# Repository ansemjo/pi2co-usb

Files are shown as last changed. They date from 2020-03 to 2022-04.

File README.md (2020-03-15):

# pi2co-usb

This project is based on [i2c-tiny-usb](https://github.com/harbaum/I2C-Tiny-USB/) by Till Harbaum and the [V-USB stack](https://www.obdev.at/products/vusb/index.html) by Objective Development. It uses the fact that you can implement a low-speed USB device with the IO pins on an Atmel AVR chip to create a very simple I2C bridge.

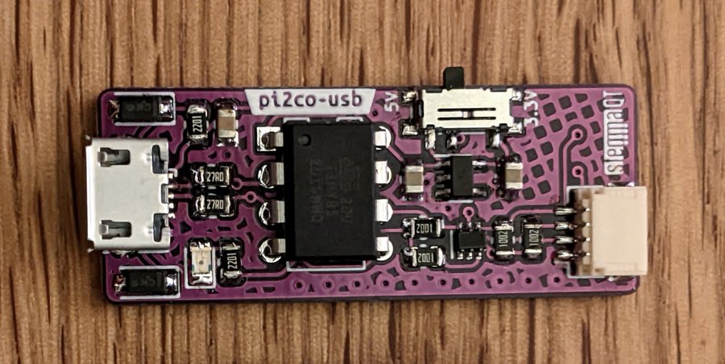
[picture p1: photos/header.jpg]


## Hardware

In the original `i2c-tiny-usb` implementation, an Atmel AVR ATtiny45 was used with an external oscillator. Unfortunately this meant, that you needed to use all six pins on the chip, reconfigure the RESET pin and therefore needed a high-voltage serial programmer (HVSP) should anything go wrong.

On more recent Digispark devices, which use an ATtiny85, a modified version of the V-USB stack is used with only the internal PLL oscillator calibrated to 16.5 MHz. No external chrystal is required, ISP remains available and you can even connect an indicator LED on the remaining pin.

I had a couple of Atmel AVR ATtiny85V-10PU chips and a small leftover piece of protoboard. Enough to build myself an I2C bridge! I used a JST-PH connector on the I2C side, which has a slightly too narrow pitch but it works out with a 4-pin connector if you solder it at the edge of the board. Also I had lots of connectors, so I could crimp myself some cables.

Here is a simple [schematic](schematic.pdf) of the protoboard version that you see below on the photos:



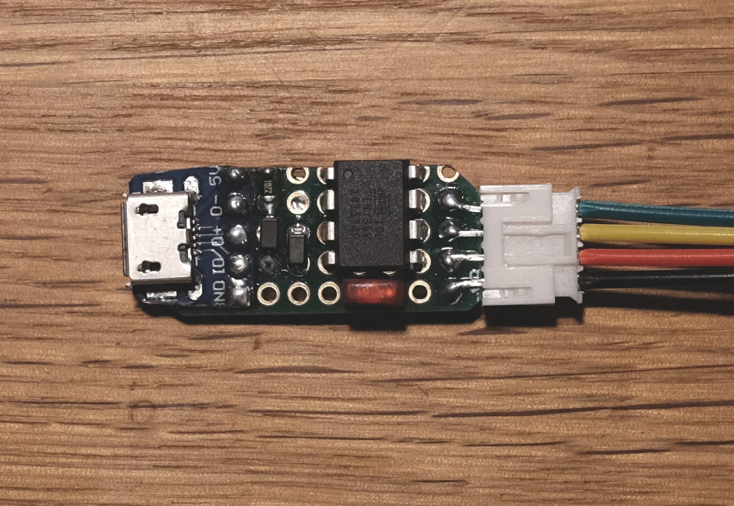
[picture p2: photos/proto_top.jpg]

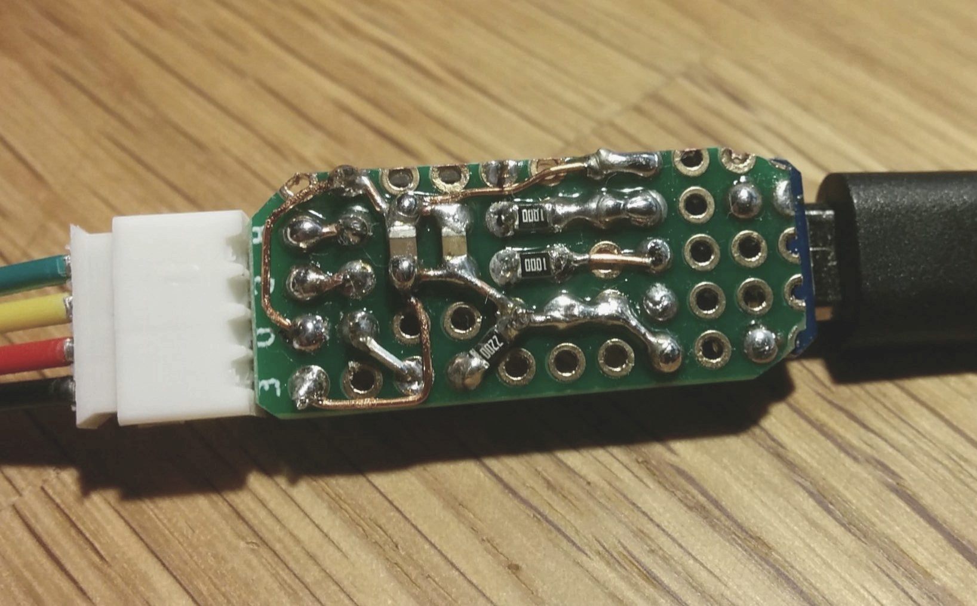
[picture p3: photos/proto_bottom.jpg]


## Software

The firmware is almost fully plucked from Till Harbaum's `i2c-tiny-usb` project, so most credit goes to him. I converted the directory to a PlatformIO project, updated the vendored V-USB stack and modified the configuration header to use a different pinout.

It is meant to work together with a current [micronucleus](https://github.com/micronucleus/micronucleus/) bootloader, which allows loading new firmware over the same USB port that is used in the userspace firmware. This implementation also relies on the oscillator calibration included in the bootloader to achieve a stable 16.5 MHz clock.

### Flash the Bootloader

At first I used a default release for the ATtiny85 that I flashed with an ISP programmer and later changed a few options to enable the indicator LED, enter the bootloader only after shorting the RESET pin and disable the timeout. The configuration can be found in `bootloader/t85_pi2co` and can be linked or copied to a micronucleus project under `firmware/configuration/`.

For example, to compile the firmware with the config profile above and flash it with an [Adafruit FT232H breakout](https://wiki.semjonov.de/tips/arduino.html#adafruit-ftdi-ft232h-breakout-board):

```sh
make clean
make CONFIG=t85_pi2co
make CONFIG=t85_pi2co PROGRAMMER="-c ft232h" flash
make CONFIG=t85_pi2co PROGRAMMER="-c ft232h" fuse
```

After that you should be able to speak to the chip with the `micronucleus` commandline application if you connect a USB breakout appropriately. **To enter the bootloader later**, you'll need to reset the chip by briefly shorting the RESET pin to ground.

To allow normal users to speak with the bootloader, apply the
udev rules found in [49-micronucleus.rules](https://github.com/micronucleus/micronucleus/blob/e74ce6f064e0bcbe1c52459a0988187c76834222/commandline/49-micronucleus.rules).

### Flash the Firmware

Now that the bootloader works, install [PlatformIO](https://platformio.org/) and go to the `firmware/` directory. You can now compile the firmware simply by running `pio run`. PlatformIO should handle all framework and platform dependencies for you.

Afterwards flash the firmware by running:

```sh
pio run -t upload
```

**Note:** PlatformIO currently ships an outdated version of the `micronucleus` commandline tool, which won't speak to the current bootloader releases. Either update the binary in `~/.platformio/packages/tool-micronucleus/` or use a current binary with the compiled firmware directly:

```sh
micronucleus .pio/build/tiny85/firmware.hex
```

### Kernel driver

The `i2c-tiny-usb` project has been around for a while, so it already has a driver in the mainline Linux kernel. I only needed to `modprobe i2c-dev` for the device to appear. Install the `i2c-tools` in your Linux distribution of choice and start talking to I2C devices. You may need to run the tools as `root`.

As an example I am reading the date and time from a DS3231 RTC clock:

```sh
$ sudo i2cdetect -l
[sudo] password for ansemjo: 
/* ... */
i2c-10	i2c       	i2c-tiny-usb at bus 001 device 028	I2C adapter
/* ... */

$ sudo i2cdetect -y 10
     0  1  2  3  4  5  6  7  8  9  a  b  c  d  e  f
00:          -- -- -- -- -- -- -- -- -- -- -- -- -- 
10: -- -- -- -- -- -- -- -- -- -- -- -- -- -- -- -- 
20: -- -- -- -- -- -- -- -- -- -- -- -- -- -- -- -- 
30: -- -- -- -- -- -- -- -- -- -- -- -- -- -- -- -- 
40: -- -- -- -- -- -- -- -- -- -- -- -- -- -- -- -- 
50: -- -- -- -- -- -- -- 57 -- -- -- -- -- -- -- -- 
60: -- -- -- -- -- -- -- -- 68 -- -- -- -- -- -- --  << this is the rtc
70: -- -- -- -- -- -- -- --                         

$ i=0; for value in seconds minutes hours weekday day month year; do \
> printf '%7s: %s\n' $value "$(sudo i2cget -y 10 0x68 $i)"; : $((i++)); done
seconds: 0x39
minutes: 0x07
  hours: 0x19
weekday: 0x07
    day: 0x15
  month: 0x03
   year: 0x20
```

The bytes need BCD decoding but you can see the date was `2020-03-15 19:07:39`.

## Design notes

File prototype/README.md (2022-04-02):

# pi2co-usb

This project is based on [i2c-tiny-usb](https://github.com/harbaum/I2C-Tiny-USB/) by Till Harbaum and the [V-USB stack](https://www.obdev.at/products/vusb/index.html) by Objective Development. It uses the fact that you can implement a low-speed USB device with the IO pins on an Atmel AVR chip to create a very simple I2C bridge.

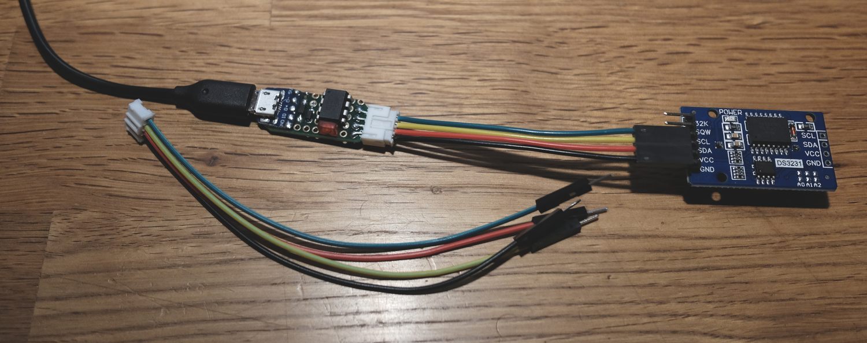
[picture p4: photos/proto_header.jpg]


## Hardware

In the original `i2c-tiny-usb` implementation, an Atmel AVR ATtiny45 was used with an external oscillator. Unfortunately this meant, that you needed to use all six pins on the chip, reconfigure the RESET pin and therefore needed a high-voltage serial programmer (HVSP) should anything go wrong.

On more recent Digispark devices, which use an ATtiny85, a modified version of the V-USB stack is used with only the internal PLL oscillator calibrated to 16.5 MHz. No external chrystal is required, ISP remains available and you can even connect an indicator LED on the remaining pin.

I had a couple of Atmel AVR ATtiny85V-10PU chips and a small leftover piece of protoboard. Enough to build myself an I2C bridge! I used a JST-PH connector on the I2C side, which has a slightly too narrow pitch but it works out with a 4-pin connector if you solder it at the edge of the board. Also I had lots of connectors, so I could crimp myself some cables.

Here is a simple [schematic](schematic.pdf) of the protoboard version that you see below on the photos:






## Software

The firmware is almost fully plucked from Till Harbaum's `i2c-tiny-usb` project, so most credit goes to him. I converted the directory to a PlatformIO project, updated the vendored V-USB stack and modified the configuration header to use a different pinout.

It is meant to work together with a current [micronucleus](https://github.com/micronucleus/micronucleus/) bootloader, which allows loading new firmware over the same USB port that is used in the userspace firmware. This implementation also relies on the oscillator calibration included in the bootloader to achieve a stable 16.5 MHz clock.

### Flash the Bootloader

At first I used a default release for the ATtiny85 that I flashed with an ISP programmer and later changed a few options to enable the indicator LED, enter the bootloader only after shorting the RESET pin and disable the timeout. The configuration can be found in `bootloader/t85_pi2co` and can be linked or copied to a micronucleus project under `firmware/configuration/`.

For example, to compile the firmware with the config profile above and flash it with an [Adafruit FT232H breakout](https://wiki.semjonov.de/tips/arduino.html#adafruit-ftdi-ft232h-breakout-board):

```sh
make clean
make CONFIG=t85_pi2co
make CONFIG=t85_pi2co PROGRAMMER="-c ft232h" flash
make CONFIG=t85_pi2co PROGRAMMER="-c ft232h" fuse
```

After that you should be able to speak to the chip with the `micronucleus` commandline application if you connect a USB breakout appropriately. **To enter the bootloader later**, you'll need to reset the chip by briefly shorting the RESET pin to ground.

To allow normal users to speak with the bootloader, apply the
udev rules found in [49-micronucleus.rules](https://github.com/micronucleus/micronucleus/blob/e74ce6f064e0bcbe1c52459a0988187c76834222/commandline/49-micronucleus.rules).

### Flash the Firmware

Now that the bootloader works, install [PlatformIO](https://platformio.org/) and go to the `firmware/` directory. You can now compile the firmware simply by running `pio run`. PlatformIO should handle all framework and platform dependencies for you.

Afterwards flash the firmware by running:

```sh
pio run -t upload
```

**Note:** PlatformIO currently ships an outdated version of the `micronucleus` commandline tool, which won't speak to the current bootloader releases. Either update the binary in `~/.platformio/packages/tool-micronucleus/` or use a current binary with the compiled firmware directly:

```sh
micronucleus .pio/build/tiny85/firmware.hex
```

### Kernel driver

The `i2c-tiny-usb` project has been around for a while, so it already has a driver in the mainline Linux kernel. I only needed to `modprobe i2c-dev` for the device to appear. Install the `i2c-tools` in your Linux distribution of choice and start talking to I2C devices. You may need to run the tools as `root`.

As an example I am reading the date and time from a DS3231 RTC clock:

```sh
$ sudo i2cdetect -l
[sudo] password for ansemjo: 
/* ... */
i2c-10	i2c       	i2c-tiny-usb at bus 001 device 028	I2C adapter
/* ... */

$ sudo i2cdetect -y 10
     0  1  2  3  4  5  6  7  8  9  a  b  c  d  e  f
00:          -- -- -- -- -- -- -- -- -- -- -- -- -- 
10: -- -- -- -- -- -- -- -- -- -- -- -- -- -- -- -- 
20: -- -- -- -- -- -- -- -- -- -- -- -- -- -- -- -- 
30: -- -- -- -- -- -- -- -- -- -- -- -- -- -- -- -- 
40: -- -- -- -- -- -- -- -- -- -- -- -- -- -- -- -- 
50: -- -- -- -- -- -- -- 57 -- -- -- -- -- -- -- -- 
60: -- -- -- -- -- -- -- -- 68 -- -- -- -- -- -- --  << this is the rtc
70: -- -- -- -- -- -- -- --                         

$ i=0; for value in seconds minutes hours weekday day month year; do \
> printf '%7s: %s\n' $value "$(sudo i2cget -y 10 0x68 $i)"; : $((i++)); done
seconds: 0x39
minutes: 0x07
  hours: 0x19
weekday: 0x07
    day: 0x15
  month: 0x03
   year: 0x20
```

The bytes need BCD decoding but you can see the date was `2020-03-15 19:07:39`.

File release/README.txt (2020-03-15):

These release files were compiled on 2020-03-15 using the steps
detailed in the project's README.md.

01. Flash the Bootloader
========================

First, flash the bootloader with your favourite ISP programming
method with avrdude. Personally, I like using an Adafruit FT232H
breakout for this:

  avrdude -c UM232H -p t85 -U flash:w:bootloader.hex:i

Don't forget to set the fuses if this is the first time flashing
micronucleus:

  avrdude -c UM232H -p t85 \
    -U lfuse:w:0xe1:m -U hfuse:w:0xdd:m -U efuse:w:0xfe:m

02. Verify USB connection
=========================

Connect a USB breakout to the ATtiny85 to verify that the command-
line tool can speak to the micronucleus bootloader. The pull-up
resistor on D- is required but depending on your computer you may
be fine without the zener diodes. This is not to specification though!

  VCC -->  VCC (pin 8)
  D-  -->  PB3 (pin 2)
  D+  -->  PB4 (pin 3)
  GND -->  GND (pin 4)

You should see a device appear on the bus and micronucleus should
be able to program the chip:

  micronucleus --erase-only

03. Upload the Firmware
=======================

Now use micronucleus to upload the firmware:

  micronucleus ./firmware.hex

After you have uploaded the firmware and replugged the USB cable, the
chip should execute the firmware immediately and the i2c-tiny-usb
should appear on the bus:

  ID 0403:c631 Future Technology Devices International, Ltd i2c-tiny-usb interface

To re-enter the bootloader, briefly short the RESET pin (pin 1) to
GND with some tweezers, for example.

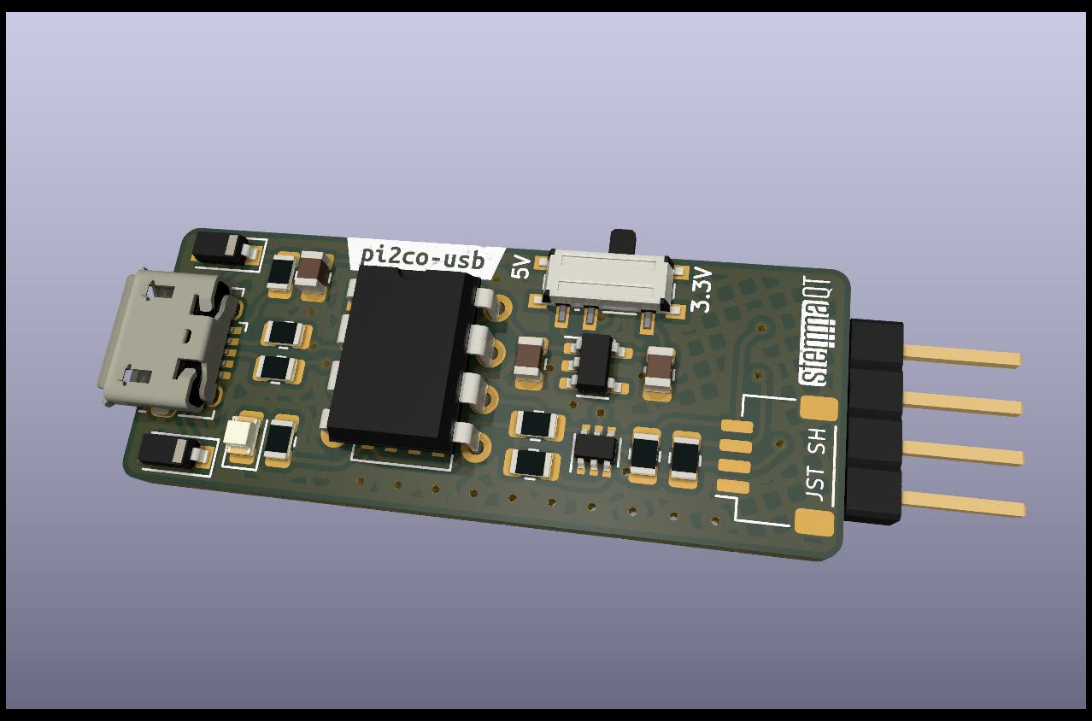
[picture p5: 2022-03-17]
hardware/render.jpg

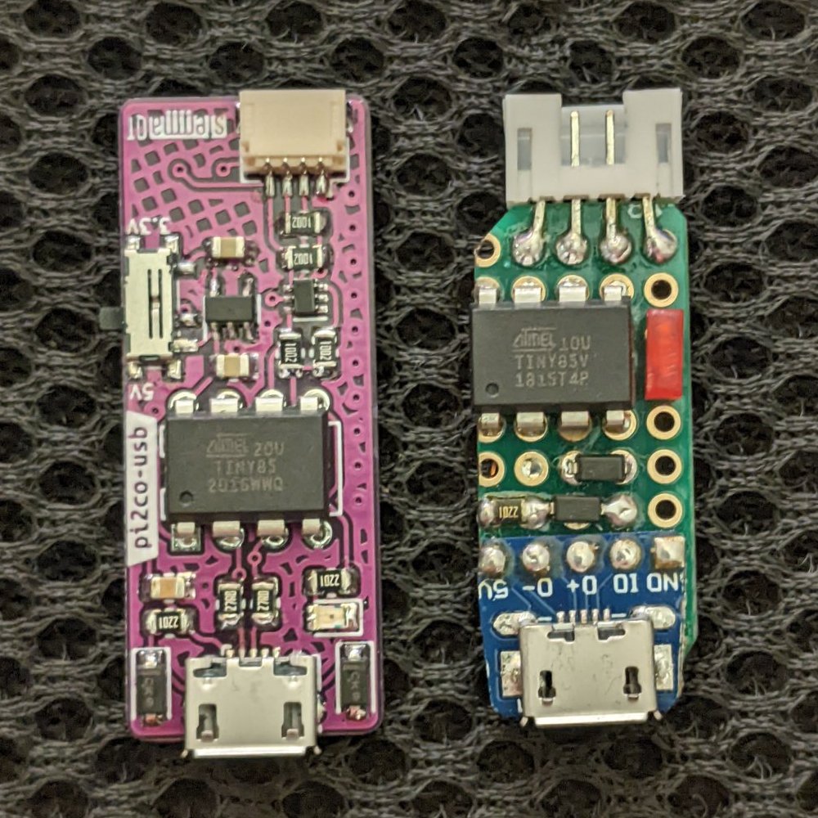
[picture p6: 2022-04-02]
photos/side-by-side-top.jpg

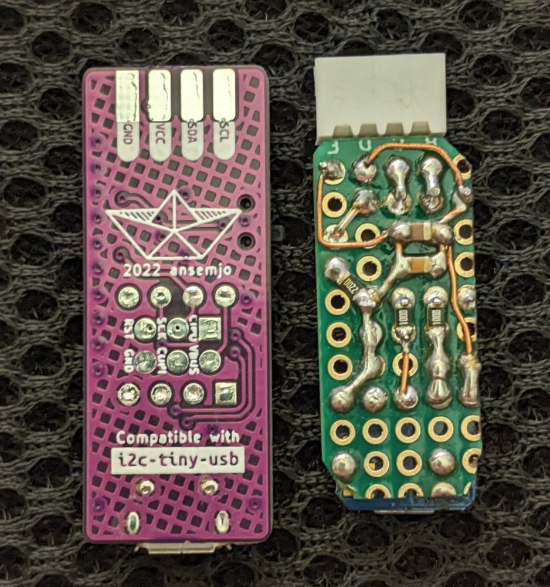
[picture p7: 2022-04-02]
photos/side-by-side-bottom.jpg

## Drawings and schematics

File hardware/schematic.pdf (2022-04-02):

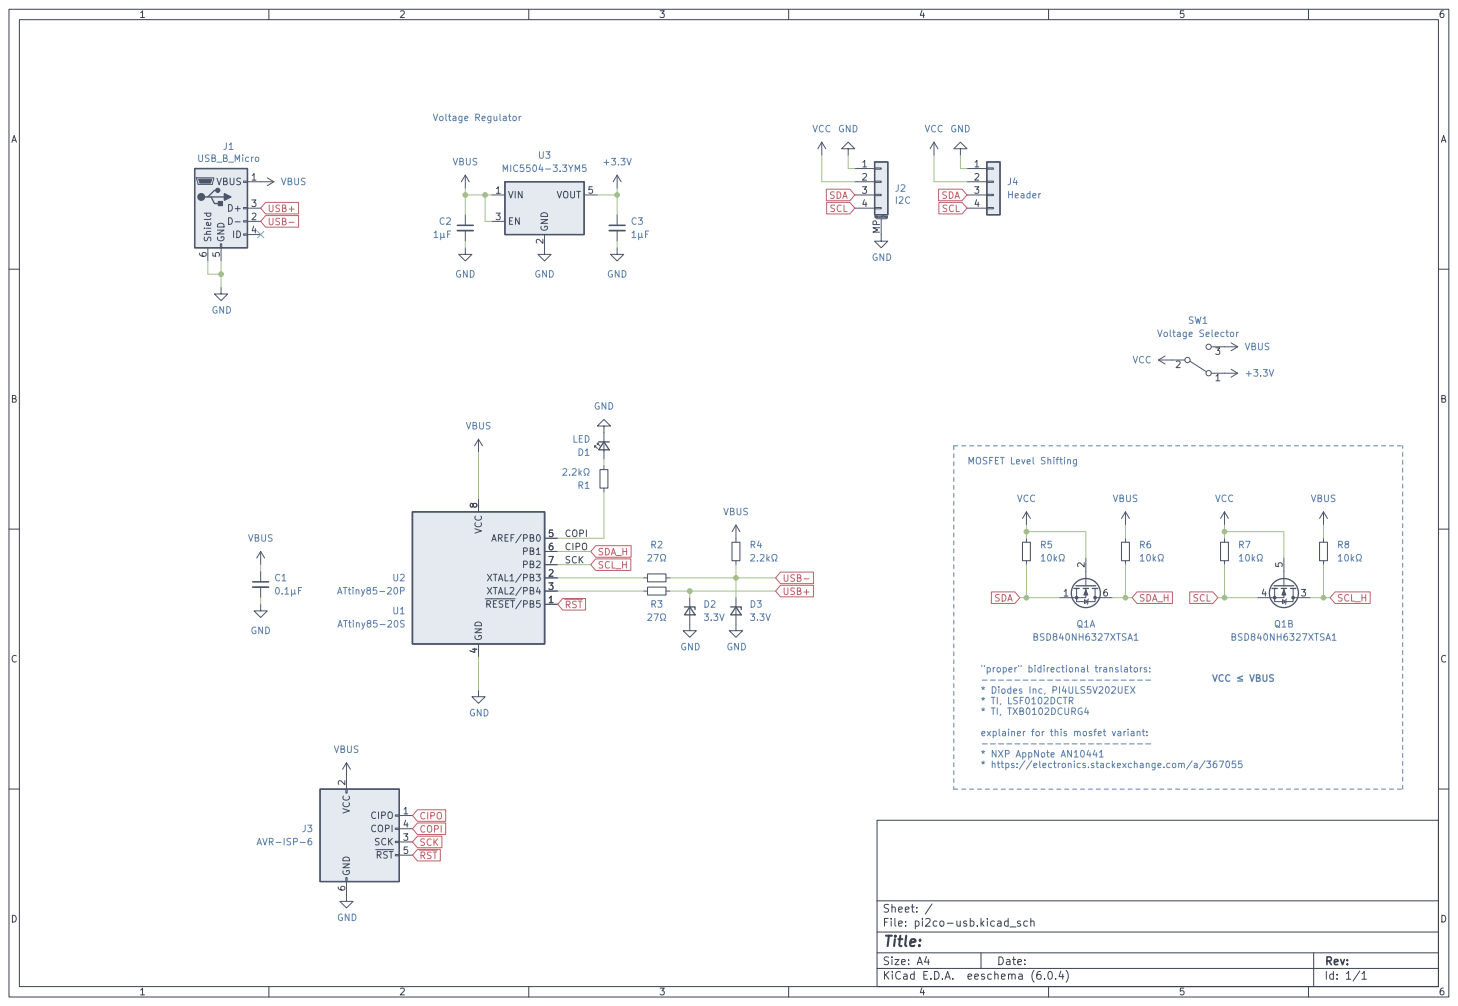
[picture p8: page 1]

"proper" bidirectional translators: --------------------- * Diodes Inc, PI4ULS5V202UEX

explainer for this mosfet variant: --------------------- * NXP AppNote AN10441

* https://electronics.stackexchange.com/a/367055

2 SCK 3 COPI 4 ~{RST} 5 GND

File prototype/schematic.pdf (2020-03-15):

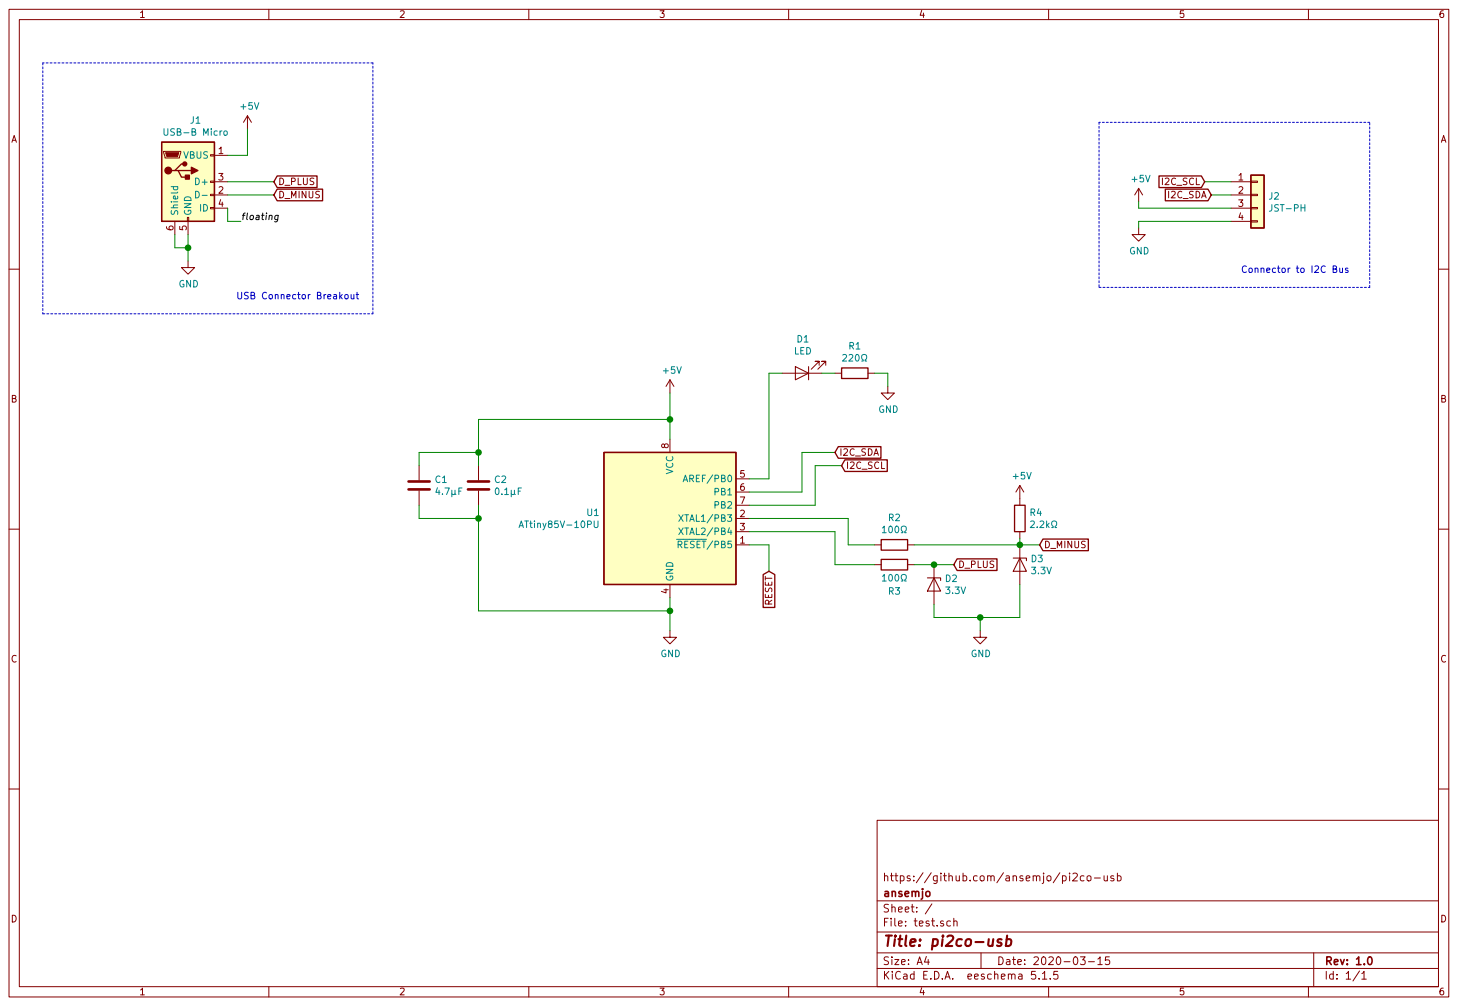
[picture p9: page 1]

https://github.com/ansemjo/pi2co-usb
File: test.sch Sheet: / ansemjo

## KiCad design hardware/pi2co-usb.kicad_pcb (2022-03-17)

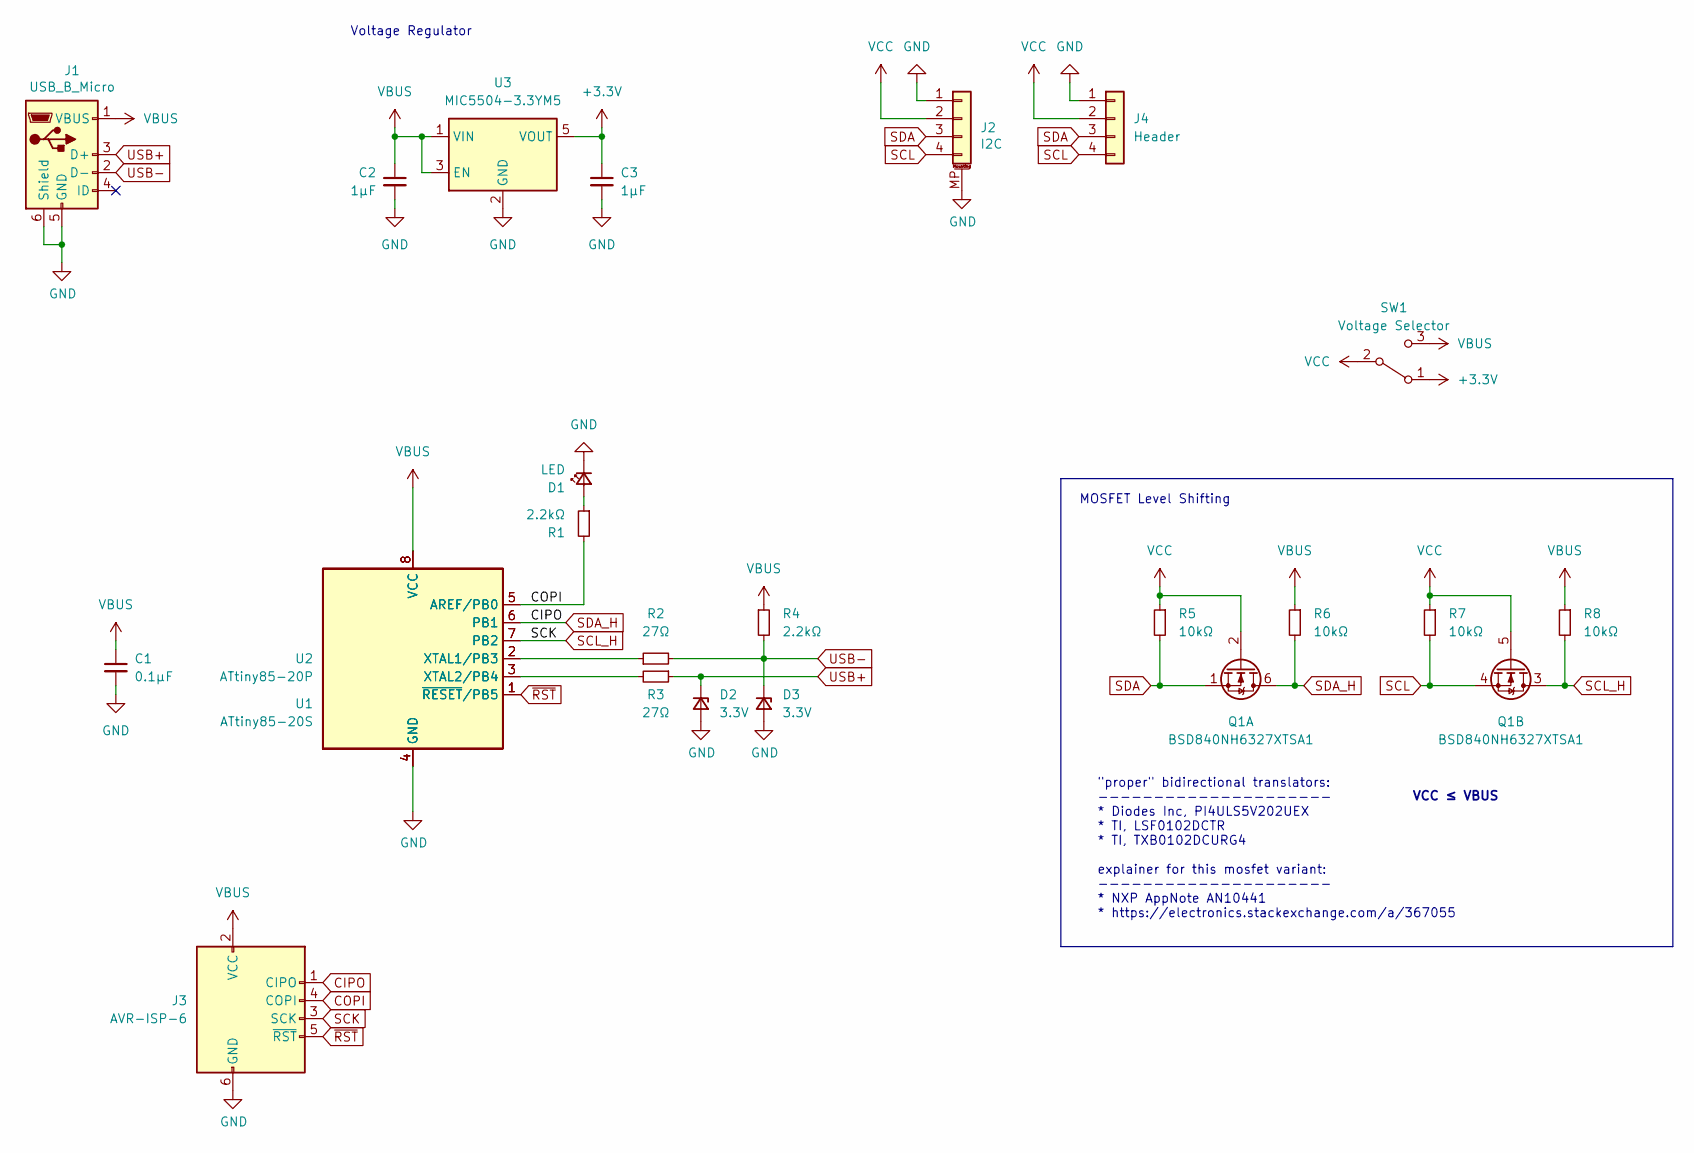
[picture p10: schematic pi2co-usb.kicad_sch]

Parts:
C1: 0.1µF; C_0805_2012Metric
C2, C3: 1µF; C_0805_2012Metric
D1: LED; LED_0805_2012Metric
D2, D3: 3.3V; D_SOD-123
J1: USB_B_Micro; USB_Micro-B_Amphenol_10118194_Horizontal
J2: I2C; JST_SH_SM04B-SRSS-TB_1x04-1MP_P1.00mm_Horizontal
J3: AVR-ISP-6; PinHeader_2x03_P2.54mm_Vertical
J4: Header; PinHeader_1x04_P2.54mm_Vertical
Q1: BSD840NH6327XTSA1; SOT-363_SC-70-6
R1, R4: 2.2kΩ; R_0805_2012Metric
R2, R3: 27Ω; R_0805_2012Metric
R5, R6, R7, R8: 10kΩ; R_0805_2012Metric
SW1: Voltage Selector; SW_SPDT_PCM12
U1: ATtiny85-20S; SOIC-8W_5.3x5.3mm_P1.27mm
U2: ATtiny85-20P; DIP-8_W7.62mm
U3: MIC5504-3.3YM5; SOT-23-5

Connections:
+3V3: C3.1, SW1.1 (A), U3.5 (VOUT)
CIPO: J3.1 (CIPO), Q1.6 (D), R6.2, U1.6 (PB1), U2.6 (PB1)
COPI: J3.4 (COPI), R1.2, U1.5 (AREF/PB0), U2.5 (AREF/PB0)
GND: C1.2, C2.2, C3.2, D1.1 (K), D2.2 (A), D3.2 (A), J1.5 (GND), J1.6 (Shield), J2.1, J2.MP (MountPin), J3.6 (GND), J4.1, U1.4 (GND), U2.4 (GND), U3.2 (GND)
unnamed: D1.2 (A), R1.1
unnamed: R2.1, U1.2 (XTAL1/PB3), U2.2 (XTAL1/PB3)
unnamed: R3.2, U1.3 (XTAL2/PB4), U2.3 (XTAL2/PB4)
SCK: J3.3 (SCK), Q1.3 (D), R8.2, U1.7 (PB2), U2.7 (PB2)
SCL: J2.4, J4.4, Q1.4 (S), R7.2
SDA: J2.3, J4.3, Q1.1 (S), R5.2
USB+: D2.1 (K), J1.3 (D+), R3.1
USB-: D3.1 (K), J1.2 (D-), R2.2, R4.2
VBUS: C1.1, C2.1, J1.1 (VBUS), J3.2 (VCC), R4.1, R6.1, R8.1, SW1.3 (C), U1.8 (VCC), U2.8 (VCC), U3.1 (VIN), U3.3 (EN)
VCC: J2.2, J4.2, Q1.2 (G), Q1.5 (G), R5.1, R7.1, SW1.2 (B)
~RST: J3.5 (~RST), U1.1 (~RESET/PB5), U2.1 (~RESET/PB5)

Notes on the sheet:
Voltage Regulator
MOSFET Level Shifting
VCC ≤ VBUS
"proper" bidirectional translators: --------------------- * Diodes Inc, PI4ULS5V202UEX * TI, LSF0102DCTR * TI, TXB0102DCURG4 explainer for this mosfet variant: --------------------- * NXP AppNote AN10441 * https://electronics.stackexchange.com/a/367055

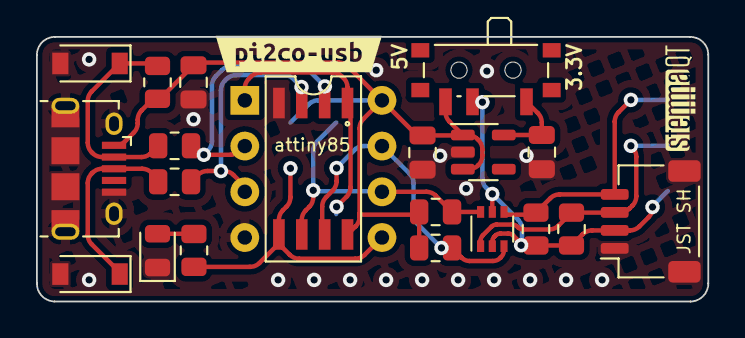
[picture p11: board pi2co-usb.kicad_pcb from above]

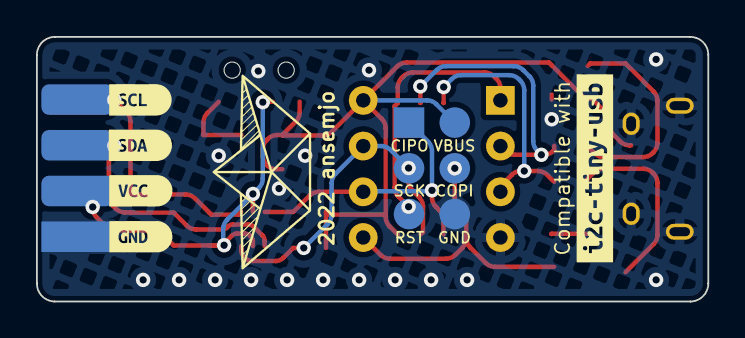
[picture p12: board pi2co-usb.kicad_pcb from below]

Board: 2 copper layers, 37.3 x 14.7 mm, 29 parts (7 on the bottom side), 15 nets.

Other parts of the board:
kibuzzard-6233B94D: G***; kibuzzard-6233B94D
kibuzzard-6233B95A: G***; kibuzzard-6233B95A
kibuzzard-6233B920: G***; kibuzzard-6233B920
kibuzzard-6233B938: G***; kibuzzard-6233B938
kibuzzard-6233BAEE: G***; kibuzzard-6233BAEE
kibuzzard-6233C230: G***; kibuzzard-6233C230

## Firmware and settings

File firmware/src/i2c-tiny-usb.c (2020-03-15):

/* Name: main.c
 * Project: i2c-tiny-usb
 * Author: Till Harbaum
 * Tabsize: 4
 * Copyright: (c) 2005 by Till Harbaum <till@harbaum.org>
 * Modified: 2020 ansemjo
 * License: GPL
 * This Revision: $Id: main.c,v 1.9 2007/06/07 13:53:47 harbaum Exp $
 *
 * $Log: main.c,v $
 *
 * 2020/03/14 ansemjo
 * Include updated V-USB stack and changed pin definitions.
 *
 * Revision 1.9  2007/06/07 13:53:47  harbaum
 * Version number fixes
 *
 * Revision 1.8  2007/05/19 12:30:11  harbaum
 * Updated USB stacks
 *
 * Revision 1.7  2007/04/22 10:34:05  harbaum
 * *** empty log message ***
 *
 * Revision 1.6  2007/01/05 19:30:58  harbaum
 * i2c clock bug fix
 *
 * Revision 1.5  2007/01/03 18:35:07  harbaum
 * usbtiny fixes and pcb layouts
 *
 * Revision 1.4  2006/12/03 21:28:59  harbaum
 * *** empty log message ***
 *
 * Revision 1.3  2006/11/22 19:12:45  harbaum
 * Added usbtiny support
 *
 * Revision 1.2  2006/11/14 19:15:13  harbaum
 * *** empty log message ***
 *
 */

#include <stdio.h>
#include <ctype.h>
#include <string.h>

#include <avr/io.h>
#include <avr/interrupt.h>
#include <avr/pgmspace.h>
#include <avr/wdt.h>

#include <util/delay.h>

#include "usbconfig.h"
#include "usbdrv/usbdrv.h"
//#include "oddebug.h"

#define ENABLE_SCL_EXPAND

/* commands from USB, must e.g. match command ids in kernel driver */
#define CMD_ECHO       0
#define CMD_GET_FUNC   1
#define CMD_SET_DELAY  2
#define CMD_GET_STATUS 3

#define CMD_I2C_IO     4
#define CMD_I2C_BEGIN  1  // flag fo I2C_IO
#define CMD_I2C_END    2  // flag fo I2C_IO

/* linux kernel flags */
#define I2C_M_TEN		0x10	/* we have a ten bit chip address */
#define I2C_M_RD		0x01
#define I2C_M_NOSTART		0x4000
#define I2C_M_REV_DIR_ADDR	0x2000
#define I2C_M_IGNORE_NAK	0x1000
#define I2C_M_NO_RD_ACK		0x0800

/* To determine what functionality is present */
#define I2C_FUNC_I2C			0x00000001
#define I2C_FUNC_10BIT_ADDR		0x00000002
#define I2C_FUNC_PROTOCOL_MANGLING	0x00000004 /* I2C_M_{REV_DIR_ADDR,NOSTART,..} */
#define I2C_FUNC_SMBUS_HWPEC_CALC	0x00000008 /* SMBus 2.0 */
#define I2C_FUNC_SMBUS_READ_WORD_DATA_PEC  0x00000800 /* SMBus 2.0 */ 
#define I2C_FUNC_SMBUS_WRITE_WORD_DATA_PEC 0x00001000 /* SMBus 2.0 */ 
#define I2C_FUNC_SMBUS_PROC_CALL_PEC	0x00002000 /* SMBus 2.0 */
#define I2C_FUNC_SMBUS_BLOCK_PROC_CALL_PEC 0x00004000 /* SMBus 2.0 */
#define I2C_FUNC_SMBUS_BLOCK_PROC_CALL	0x00008000 /* SMBus 2.0 */
#define I2C_FUNC_SMBUS_QUICK		0x00010000 
#define I2C_FUNC_SMBUS_READ_BYTE	0x00020000 
#define I2C_FUNC_SMBUS_WRITE_BYTE	0x00040000 
#define I2C_FUNC_SMBUS_READ_BYTE_DATA	0x00080000 
#define I2C_FUNC_SMBUS_WRITE_BYTE_DATA	0x00100000 
#define I2C_FUNC_SMBUS_READ_WORD_DATA	0x00200000 
#define I2C_FUNC_SMBUS_WRITE_WORD_DATA	0x00400000 
#define I2C_FUNC_SMBUS_PROC_CALL	0x00800000 
#define I2C_FUNC_SMBUS_READ_BLOCK_DATA	0x01000000 
#define I2C_FUNC_SMBUS_WRITE_BLOCK_DATA 0x02000000 
#define I2C_FUNC_SMBUS_READ_I2C_BLOCK	0x04000000 /* I2C-like block xfer  */
#define I2C_FUNC_SMBUS_WRITE_I2C_BLOCK	0x08000000 /* w/ 1-byte reg. addr. */
#define I2C_FUNC_SMBUS_READ_I2C_BLOCK_2	 0x10000000 /* I2C-like block xfer  */
#define I2C_FUNC_SMBUS_WRITE_I2C_BLOCK_2 0x20000000 /* w/ 2-byte reg. addr. */
#define I2C_FUNC_SMBUS_READ_BLOCK_DATA_PEC  0x40000000 /* SMBus 2.0 */
#define I2C_FUNC_SMBUS_WRITE_BLOCK_DATA_PEC 0x80000000 /* SMBus 2.0 */

#define I2C_FUNC_SMBUS_BYTE I2C_FUNC_SMBUS_READ_BYTE | \
                            I2C_FUNC_SMBUS_WRITE_BYTE
#define I2C_FUNC_SMBUS_BYTE_DATA I2C_FUNC_SMBUS_READ_BYTE_DATA | \
                                 I2C_FUNC_SMBUS_WRITE_BYTE_DATA
#define I2C_FUNC_SMBUS_WORD_DATA I2C_FUNC_SMBUS_READ_WORD_DATA | \
                                 I2C_FUNC_SMBUS_WRITE_WORD_DATA
#define I2C_FUNC_SMBUS_BLOCK_DATA I2C_FUNC_SMBUS_READ_BLOCK_DATA | \
                                  I2C_FUNC_SMBUS_WRITE_BLOCK_DATA
#define I2C_FUNC_SMBUS_I2C_BLOCK I2C_FUNC_SMBUS_READ_I2C_BLOCK | \
                                  I2C_FUNC_SMBUS_WRITE_I2C_BLOCK

#define I2C_FUNC_SMBUS_EMUL I2C_FUNC_SMBUS_QUICK | \
                            I2C_FUNC_SMBUS_BYTE | \
                            I2C_FUNC_SMBUS_BYTE_DATA | \
                            I2C_FUNC_SMBUS_WORD_DATA | \
                            I2C_FUNC_SMBUS_PROC_CALL | \
                            I2C_FUNC_SMBUS_WRITE_BLOCK_DATA | \
                            I2C_FUNC_SMBUS_WRITE_BLOCK_DATA_PEC | \
                            I2C_FUNC_SMBUS_I2C_BLOCK

/* the currently support capability is quite limited */
const unsigned long func PROGMEM = I2C_FUNC_I2C | I2C_FUNC_SMBUS_EMUL;

#ifdef DEBUG
#define DEBUGF(format, args...) printf_P(PSTR(format), ##args)

/* ------------------------------------------------------------------------- */
static int uart_putchar(char c, FILE *stream) {
  if (c == '\n')
    uart_putchar('\r', stream);
  loop_until_bit_is_set(UCSRA, UDRE);
  UDR = c;
  return 0;
}

static FILE mystdout = FDEV_SETUP_STREAM(uart_putchar, NULL,
                                         _FDEV_SETUP_WRITE);
#else
#define DEBUGF(format, args...)
#endif

/* ------------------------------------------------------------------------- */
#define DEFAULT_DELAY 10  // default 10us (100khz)
static unsigned short clock_delay  = DEFAULT_DELAY;
static unsigned short clock_delay2 = DEFAULT_DELAY/2;

static unsigned short expected;
static unsigned char saved_cmd;

#if defined (__AVR_ATtiny85__) 
#define I2C_PORT   PORTB
#define I2C_PIN    PINB
#define I2C_DDR    DDRB
#define I2C_SDA    _BV(1)
#define I2C_SCL    _BV(2)
#endif

static void i2c_io_set_sda(uchar hi) {
  if(hi) {
    I2C_DDR  &= ~I2C_SDA;    // high -> input
    I2C_PORT |=  I2C_SDA;    // with pullup
  } else {
    I2C_DDR  |=  I2C_SDA;    // low -> output
    I2C_PORT &= ~I2C_SDA;    // drive low
  }
}

static uchar i2c_io_get_sda(void) {
  return(I2C_PIN & I2C_SDA);
}

static void i2c_io_set_scl(uchar hi) {
#ifdef ENABLE_SCL_EXPAND
  _delay_loop_2(clock_delay2);
  if(hi) {
    I2C_DDR &= ~I2C_SCL;          // port is input
    I2C_PORT |= I2C_SCL;          // enable pullup

    // wait while pin is pulled low by client
    while(!(I2C_PIN & I2C_SCL));
  } else {
    I2C_DDR |= I2C_SCL;           // port is output
    I2C_PORT &= ~I2C_SCL;         // drive it low
  }
  _delay_loop_2(clock_delay);
#else
  _delay_loop_2(clock_delay2);
  if(hi) I2C_PORT |=  I2C_SCL;    // port is high
  else   I2C_PORT &= ~I2C_SCL;    // port is low
  _delay_loop_2(clock_delay);
#endif
}

static void i2c_init(void) {
  /* init the sda/scl pins */
  I2C_DDR &= ~I2C_SDA;            // port is input
  I2C_PORT |= I2C_SDA;            // enable pullup
#ifdef ENABLE_SCL_EXPAND
  I2C_DDR &= ~I2C_SCL;            // port is input
  I2C_PORT |= I2C_SCL;            // enable pullup
#else
  I2C_DDR |= I2C_SCL;             // port is output
#endif

  /* no bytes to be expected */
  expected = 0;
}

/* clock HI, delay, then LO */
static void i2c_scl_toggle(void) {
  i2c_io_set_scl(1);
  i2c_io_set_scl(0);
}

/* i2c start condition */
static void i2c_start(void) {
  i2c_io_set_sda(0);
  i2c_io_set_scl(0);
}

/* i2c repeated start condition */
static void i2c_repstart(void) 
{
  /* scl, sda may not be high */
  i2c_io_set_sda(1);
  i2c_io_set_scl(1);
  
  i2c_io_set_sda(0);
  i2c_io_set_scl(0);
}

/* i2c stop condition */
void i2c_stop(void) {
  i2c_io_set_sda(0);
  i2c_io_set_scl(1);
  i2c_io_set_sda(1);
}

uchar i2c_put_u08(uchar b) {
  char i;

  for (i=7;i>=0;i--) {
    if ( b & (1<<i) )  i2c_io_set_sda(1);
    else               i2c_io_set_sda(0);
    
    i2c_scl_toggle();           // clock HI, delay, then LO
  }
  
  i2c_io_set_sda(1);            // leave SDL HI
  i2c_io_set_scl(1);            // clock back up

  b = i2c_io_get_sda();         // get the ACK bit
  i2c_io_set_scl(0);            // not really ??

  return(b == 0);               // return ACK value
}

uchar i2c_get_u08(uchar last) {
  char i;
  uchar c,b = 0;

  i2c_io_set_sda(1);            // make sure pullups are activated
  i2c_io_set_scl(0);            // clock LOW

  for(i=7;i>=0;i--) {
    i2c_io_set_scl(1);          // clock HI
    c = i2c_io_get_sda();
    b <<= 1;
    if(c) b |= 1;
    i2c_io_set_scl(0);          // clock LO
  }

  if(last) i2c_io_set_sda(1);   // set NAK
  else     i2c_io_set_sda(0);   // set ACK

  i2c_scl_toggle();             // clock pulse
  i2c_io_set_sda(1);            // leave with SDL HI

  return b;                     // return received byte
}

#ifdef DEBUG
void i2c_scan(void) {
  uchar i = 0;

  for(i=0;i<127;i++) {
    i2c_start();                  // do start transition
    if(i2c_put_u08(i << 1))       // send DEVICE address
      DEBUGF("I2C device at address 0x%x\n", i);

    i2c_stop();
  }
}
#endif

/* ------------------------------------------------------------------------- */

struct i2c_cmd {
  unsigned char type;
  unsigned char cmd;
  unsigned short flags;
  unsigned short addr;
  unsigned short len;  
};

#define STATUS_IDLE          0
#define STATUS_ADDRESS_ACK   1
#define STATUS_ADDRESS_NAK   2

static uchar status = STATUS_IDLE;

static uchar i2c_do(struct i2c_cmd *cmd) {
  uchar addr;

  DEBUGF("i2c %s at 0x%02x, len = %d\n", 
	   (cmd->flags&I2C_M_RD)?"rd":"wr", cmd->addr, cmd->len); 

  /* normal 7bit address */
  addr = ( cmd->addr << 1 );
  if (cmd->flags & I2C_M_RD )
    addr |= 1;

  if(cmd->cmd & CMD_I2C_BEGIN) 
    i2c_start();
  else 
    i2c_repstart();    

  // send DEVICE address
  if(!i2c_put_u08(addr)) {
    DEBUGF("I2C read: address error @ %x\n", addr);

    status = STATUS_ADDRESS_NAK;
    expected = 0;
    i2c_stop();
  } else {  
    status = STATUS_ADDRESS_ACK;
    expected = cmd->len;
    saved_cmd = cmd->cmd;

    /* check if transfer is already done (or failed) */
    if((cmd->cmd & CMD_I2C_END) && !expected) 
      i2c_stop();
  }

  /* more data to be expected? */
#ifndef USBTINY
  return(cmd->len?0xff:0x00);
#else
  return(((cmd->flags & I2C_M_RD) && cmd->len)?0xff:0x00);
#endif
}

#ifndef USBTINY
uchar	usbFunctionSetup(uchar data[8]) {
  static uchar replyBuf[4];
  usbMsgPtr = replyBuf;
#else
extern	byte_t	usb_setup ( byte_t data[8] )
{
  byte_t *replyBuf = data;
#endif

  DEBUGF("Setup %x %x %x %x\n", data[0], data[1], data[2], data[3]);

  switch(data[1]) {

  case CMD_ECHO: // echo (for transfer reliability testing)
    replyBuf[0] = data[2];
    replyBuf[1] = data[3];
    return 2;
    break;

  case CMD_GET_FUNC:
    memcpy_P(replyBuf, &func, sizeof(func));
    return sizeof(func);
    break;

  case CMD_SET_DELAY:
    /* The delay function used delays 4 system ticks per cycle. */
    /* This gives 1/3us at 12Mhz per cycle. The delay function is */
    /* called twice per clock edge and thus four times per full cycle. */ 
    /* Thus it is called one time per edge with the full delay */ 
    /* value and one time with the half one. Resulting in */
    /* 2 * n * 1/3 + 2 * 1/2 n * 1/3 = n us. */
    clock_delay = *(unsigned short*)(data+2);
    if(!clock_delay) clock_delay = 1;
    clock_delay2 = clock_delay/2;
    if(!clock_delay2) clock_delay2 = 1;

    DEBUGF("request for delay %dus\n", clock_delay); 
    break;

  case CMD_I2C_IO:
  case CMD_I2C_IO + CMD_I2C_BEGIN:
  case CMD_I2C_IO                 + CMD_I2C_END:
  case CMD_I2C_IO + CMD_I2C_BEGIN + CMD_I2C_END:
    // these are only allowed as class transfers

    return i2c_do((struct i2c_cmd*)data);
    break;

  case CMD_GET_STATUS:
    replyBuf[0] = status;
    return 1;
    break;

  default:
    // must not happen ...
    break;
  }

  return 0;  // reply len
}


/*---------------------------------------------------------------------------*/
/* usbFunctionRead                                                           */
/*---------------------------------------------------------------------------*/

#ifndef USBTINY
uchar usbFunctionRead( uchar *data, uchar len )
#else
extern	byte_t	usb_in ( byte_t* data, byte_t len )
#endif
{
  uchar i;

  DEBUGF("read %d bytes, %d exp\n", len, expected);

  if(status == STATUS_ADDRESS_ACK) {
    if(len > expected) {
      DEBUGF("exceeds!\n");
      len = expected;
    }

    // consume bytes
    for(i=0;i<len;i++) {
      expected--;
      *data = i2c_get_u08(expected == 0);
      DEBUGF("data = %x\n", *data);
      data++;
    }

    // end transfer on last byte
    if((saved_cmd & CMD_I2C_END) && !expected) 
      i2c_stop();

  } else {
    DEBUGF("not in ack state\n");
    memset(data, 0, len);
  }
  return len;
}

/*---------------------------------------------------------------------------*/
/* usbFunctionWrite                                                          */
/*---------------------------------------------------------------------------*/

#ifndef USBTINY
uchar usbFunctionWrite( uchar *data, uchar len )
#else
extern	void	usb_out ( byte_t* data, byte_t len )
#endif
{
  uchar i, err=0;

  DEBUGF("write %d bytes, %d exp\n", len, expected);

  if(status == STATUS_ADDRESS_ACK) {
    if(len > expected) {
      DEBUGF("exceeds!\n");
      len = expected;
    }

    // consume bytes
    for(i=0;i<len;i++) {
      expected--;
      DEBUGF("data = %x\n", *data);
      if(!i2c_put_u08(*data++))
	err = 1;
    }

    // end transfer on last byte
    if((saved_cmd & CMD_I2C_END) && !expected) 
      i2c_stop();

    if(err) {
      DEBUGF("write failed\n");
      //TODO: set status
    }

  } else {
    DEBUGF("not in ack state\n");
    memset(data, 0, len);
  }

#ifndef USBTINY
  return len;
#endif
}


/* ------------------------------------------------------------------------- */

int	main(void) {
  wdt_enable(WDTO_1S);

#if DEBUG_LEVEL > 0
  /* let debug routines init the uart if they want to */
  odDebugInit();
#else
#ifdef DEBUG
  /* quick'n dirty uart init */
  UCSRB |= _BV(TXEN);
  UBRRL = F_CPU / (19200 * 16L) - 1;
#endif
#endif

#ifdef DEBUG
  stdout = &mystdout;
#endif

  DEBUGF("i2c-tiny-usb - (c) 2006 by Till Harbaum\n");

  i2c_init();

#ifdef DEBUG
  i2c_scan();
#endif

  /* clear usb ports */
  USB_CFG_IOPORT   &= (uchar)~((1<<USB_CFG_DMINUS_BIT)|(1<<USB_CFG_DPLUS_BIT));

  /* make usb data lines outputs */
  USBDDR    |= ((1<<USB_CFG_DMINUS_BIT)|(1<<USB_CFG_DPLUS_BIT));

  /* USB Reset by device only required on Watchdog Reset */
  _delay_loop_2(40000);   // 10ms

  /* make usb data lines inputs */
  USBDDR &= ~((1<<USB_CFG_DMINUS_BIT)|(1<<USB_CFG_DPLUS_BIT));

  usbInit();

  sei();
  for(;;) {	/* main event loop */
    wdt_reset();
    usbPoll();
  }

  return 0;
}

/* ------------------------------------------------------------------------- */

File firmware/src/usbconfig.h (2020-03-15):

/* Name: usbconfig.h
 * Project: V-USB, virtual USB port for Atmel's(r) AVR(r) microcontrollers
 * Author: Christian Starkjohann
 * Creation Date: 2005-04-01
 * Tabsize: 4
 * Copyright: (c) 2005 by OBJECTIVE DEVELOPMENT Software GmbH
 * License: GNU GPL v2 (see License.txt), GNU GPL v3 or proprietary (CommercialLicense.txt)
 */

#ifndef __usbconfig_h_included__
#define __usbconfig_h_included__

/*
General Description:
This file is an example configuration (with inline documentation) for the USB
driver. It configures V-USB for USB D+ connected to Port D bit 2 (which is
also hardware interrupt 0 on many devices) and USB D- to Port D bit 4. You may
wire the lines to any other port, as long as D+ is also wired to INT0 (or any
other hardware interrupt, as long as it is the highest level interrupt, see
section at the end of this file).
+ To create your own usbconfig.h file, copy this file to your project's
+ firmware source directory) and rename it to "usbconfig.h".
+ Then edit it accordingly.
*/

/* ---------------------------- Hardware Config ---------------------------- */

#define USB_CFG_IOPORTNAME      B
/* This is the port where the USB bus is connected. When you configure it to
 * "B", the registers PORTB, PINB and DDRB will be used.
 */
#define USB_CFG_DMINUS_BIT      3
/* This is the bit number in USB_CFG_IOPORT where the USB D- line is connected.
 * This may be any bit in the port.
 */
#define USB_CFG_DPLUS_BIT       4
/* This is the bit number in USB_CFG_IOPORT where the USB D+ line is connected.
 * This may be any bit in the port. Please note that D+ must also be connected
 * to interrupt pin INT0! [You can also use other interrupts, see section
 * "Optional MCU Description" below, or you can connect D- to the interrupt, as
 * it is required if you use the USB_COUNT_SOF feature. If you use D- for the
 * interrupt, the USB interrupt will also be triggered at Start-Of-Frame
 * markers every millisecond.]
 */
#define USB_CFG_CLOCK_KHZ       (F_CPU/1000)
/* Clock rate of the AVR in kHz. Legal values are 12000, 12800, 15000, 16000,
 * 16500, 18000 and 20000. The 12.8 MHz and 16.5 MHz versions of the code
 * require no crystal, they tolerate +/- 1% deviation from the nominal
 * frequency. All other rates require a precision of 2000 ppm and thus a
 * crystal!
 * Since F_CPU should be defined to your actual clock rate anyway, you should
 * not need to modify this setting.
 */
#define USB_CFG_CHECK_CRC       0
/* Define this to 1 if you want that the driver checks integrity of incoming
 * data packets (CRC checks). CRC checks cost quite a bit of code size and are
 * currently only available for 18 MHz crystal clock. You must choose
 * USB_CFG_CLOCK_KHZ = 18000 if you enable this option.
 */

/* --------- Set up interrupt configuration for D+ (CPU specific) ------------  */

/* == NOTE: This section is copied from the micronucleus config t85_default. == */
/* The register names change quite a bit in the ATtiny family. Pay attention    */
/* to the manual. Note that the interrupt flag system is still used even though */
/* interrupts are disabled. So this has to be configured correctly.             */
#define USB_INTR_CFG            PCMSK
#define USB_INTR_CFG_SET        (1 << USB_CFG_DPLUS_BIT)
#define USB_INTR_CFG_CLR        0
#define USB_INTR_ENABLE         GIMSK
#define USB_INTR_ENABLE_BIT     PCIE
#define USB_INTR_PENDING        GIFR
#define USB_INTR_PENDING_BIT    PCIF
#define USB_INTR_VECTOR         PCINT0_vect

/* ----------------------- Optional Hardware Config ------------------------ */

/* #define USB_CFG_PULLUP_IOPORTNAME   D */
/* If you connect the 1.5k pullup resistor from D- to a port pin instead of
 * V+, you can connect and disconnect the device from firmware by calling
 * the macros usbDeviceConnect() and usbDeviceDisconnect() (see usbdrv.h).
 * This constant defines the port on which the pullup resistor is connected.
 */
/* #define USB_CFG_PULLUP_BIT          4 */
/* This constant defines the bit number in USB_CFG_PULLUP_IOPORT (defined
 * above) where the 1.5k pullup resistor is connected. See description
 * above for details.
 */

/* --------------------------- Functional Range ---------------------------- */
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

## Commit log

2020-03-15 add schematic as kicad .sch and plotted pdf/svg
    [schematic.sch]
2022-03-17 kicad project for proper pcb incl. level shifting
    [pi2co-usb.kicad_pcb, pi2co-usb.kicad_sch]
2022-04-02 add ibom.html for assembly
2022-04-02 update readme and move old schematic to prototype/
    [schematic.sch]
